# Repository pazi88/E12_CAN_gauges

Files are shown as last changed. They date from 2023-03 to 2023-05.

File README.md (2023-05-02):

# CAN-bus gauge cluster for BMW E12
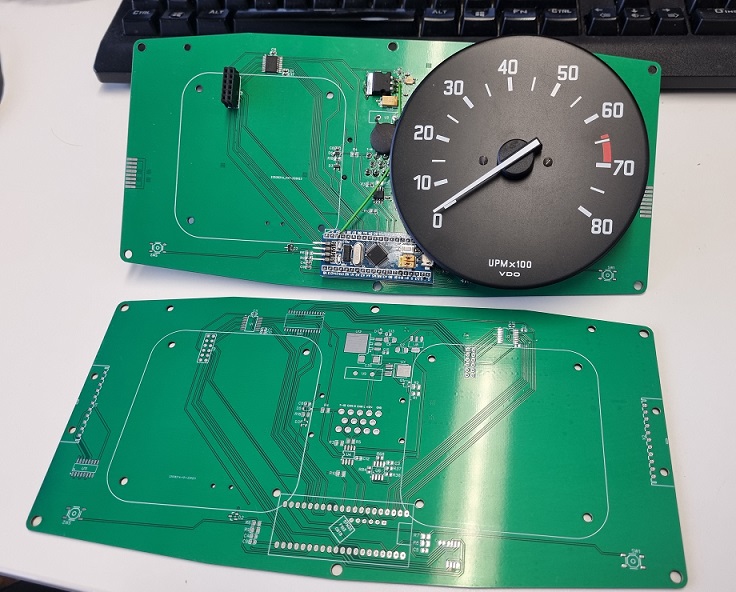
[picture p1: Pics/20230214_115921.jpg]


This is repository for CAN-bus instrument cluster for BMW E12. This is meant to replace the stock 70's mechanics/electronics inside the
cluster with x27 steppers and OLED screens to make the cluster to work with modern ECUs through CAN-bus, but retain original look.
Even though this project is meant only for E12 BMW, the code and basic circuit design can be used for other cars too.

X27.589 steppers are used to move the needles and two black and white SH1122 OLED screens are used to display odometer and trip.
The board and code can use dedicated AX1201728SG stepper driver to drive the stepper motors or TB6612FNG H-bridge driver. Both
work well, but the AX1201728SG stepper driver has micro stepping, so it will provide smoother needle movement. And allows up to 4 gauges.
MCU controlling the cluster is STM32F103C8T6 "blue pill" because of the cheap price, good availability and integrated CAN-interface.
For CAN-interface I'm using STM32 CAN library written by me: https://github.com/pazi88/STM32_CAN

CAN-bus currently supports reading data in BMW e46/e39 CAN-bus format (can11h) and also in OBD2 format.

- The OLED screen used: https://s.click.aliexpress.com/e/_DnFnmSD
- The steppers screen used: https://s.click.aliexpress.com/e/_DCNMbOH
- STM32F103C8T6: https://s.click.aliexpress.com/e/_DE6f1d3

## EasyEda
- EasyEda/OSHWLab project link for cluster back board: https://oshwlab.com/pazi88/e12_mittaristo
- EasyEda/OSHWLab project link for needle back board: https://oshwlab.com/pazi88/e12_mittaristo_copy

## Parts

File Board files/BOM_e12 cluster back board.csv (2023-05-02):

ID | Name | Designator | Footprint | Quantity | Manufacturer Part | Manufacturer | Supplier | Supplier Part | Price
1 | CR1220-2 | B1 | BAT-SMD_CR1220-2 | 1 | CR1220-2 | Q&J | LCSC | C70381 | 0.035
2 | 100nF | C1,C2,C3,C4,C5,C8,C9,C10,C11,C12,C13,C15,C16,C18,C19 | C0603 | 15 | CL10B104JB8NNNC | SAMSUNG | LCSC | C24452 | 0.001
3 | 47uF | C6,C7 | CAP-SMD_L3.5-W2.8-R-RD | 2 | CA45-B-10V-47UF-K | CEC | LCSC | C136658 | 0.015
4 | 10nF | C14,C17 | C0603 | 2 | 0603B103K500NT | FH | LCSC | C57112
5 | 10uF | C35 | CASE-E_7343 | 1 | 593D106X9050E2TE3 | Vishay Intertech | LCSC | C506619 | 0.192
6 | 776262-1 | CN1 | CONN-TH_776262-1 | 1 | 776262-1 | TE Connectivity | LCSC | C498489 | 0.88
7 | BZT52C5V6S_C173435 | D1 | SOD-323_L1.8-W1.3-LS2.5-RD | 1 | BZT52C5V6S | (MDD) Jiangsu Yutai Elec | LCSC | C173435 | 0.002
8 | BAT54CLT1G | D2,D3 | SOT-23-3_L2.9-W1.6-P1.90-LS2.8-BR | 2 | BAT54CLT1G | ON | LCSC | C14308 | 0.005
9 | BZT52C5V6_C173406 | D5 | SOD-123_L2.8-W1.8-LS3.7-RD | 1 | BZT52C5V6 | (MDD) Jiangsu Yutai Elec | LCSC | C173406 | 0.002
10 | Header-Male-2.54_2x6 | P1,P3 | HDR-TH_12P-P2.54-V-R2-C6-S2.54 | 2 |  |  | LCSC | C66689 | 0.006
11 | Serial | P2 | HDR-6X1/2.54 | 1 | Female header 1*6p | BOOMELE | LCSC | C40877 | 0.011
12 | 1K | R1,R6,R7 | R0805 | 3 | 0805W8F1001T5E | UniOhm | LCSC | C17513
13 | 4.7K | R3,R18 | R0805 | 2 | 0805W8F4701T5E | UniOhm | LCSC | C17673
14 | 10K | R4,R8,R9,R10 | R0805 | 4 | 0805W8F1002T5E | UniOhm | LCSC | C17414
15 | 120Ω | R5 | R0805 | 1 | 0805W8F1200T5E | UniOhm | LCSC | C17437
16 | 100K | R16 | R0805 | 1 | 0805W8F1003T5E | Uniroyal Elec | LCSC | C149504
17 | TS-1187A-C-G-A | SW1,SW2 | SW-SMD_4P-L5.1-W5.1-P3.70-LS6.4 | 2 | TS-1187A-C-G-A | XKB Enterprise | LCSC | C318886 | 0.009
18 | TB6612FNG(O,C,8,EL | U1,U2 | SSOP-24_L8.4-W5.8-P0.65-LS7.8-BL | 2 | TB6612FNG(O,C,8,EL | TOSHIBA | LCSC | C88224 | 0.349
19 | Blue Pill STM32F103C6T8 | U3 | BLUE PILL STM32F103C6T8 | 1
20 | MCP2551T-I/SN | U4 | SOIC-8_150MIL | 1 | MCP2551T-I/SN | MICROCHIP | LCSC | C49558 | 0.196
21 | W25Q16JVSSIQ | U5 | SOIC-8_L5.3-W5.3-P1.27-LS8.0-BL | 1 | W25Q16JVSSIQ | WINBOND | LCSC | C82317 | 0.047
22 | LD29150PT50R | U6 | TO-252-5_L6.0-W6.5-P1.27_LD29150PT50R | 1 | LD29150PT50R | ST(意法半导体) | LCSC | C3744631 | 0.159
23 | VN5R003H-E | U7 | HPAK-6_L6.1-W6.5-P0.85-LS10.0-TR | 1 | VN5R003H-E | ST(意法半导体) | LCSC | C1556752 | 0.299
24 | AMS1117-3.3 | U8 | SOT-223-3_L6.5-W3.4-P2.30-LS7.0-BR | 1 | AMS1117-3.3 | AMS | LCSC | C6186 | 0.024
25 | 14D220K | U9 | PS-RES-16.5*7.51_SMALLER | 1 | 14D220K | HEL | LCSC | C136782 | 0.011
26 | AX1201728SG | U10 | SOP-28_L17.9-W7.5-P1.27-LS10.3-BL | 1 | AX1201728SG | null | LCSC | C2841830
27 | ULN2003ADR | U11 | SOIC-16_L9.9-W3.9-P1.27-LS6.0-BL | 1 | ULN2003ADR | TI(德州仪器) | LCSC | C7512 | 0.026
28 | HEADER_POS11_?43650-1100 | X1,X2 | 43650-1100 | 2

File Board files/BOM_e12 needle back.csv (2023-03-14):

ID | Name | Designator | Footprint | Quantity | Manufacturer Part | Manufacturer | Supplier | Supplier Part | Price
1 | Header-Female-2.54_2x6 | H1 | HDR-TH_12P-P2.54-V-R2-C6-S2.54 | 1 | Header-Female-2.54_2x6 | BOOMELE | LCSC | C36191 | 0.012
2 | X27.589 | M1 | X27.589 | 1
3 | 2.08 256x64 25664 SH1122 Oled Screen Display | OLED1,OLED2 | 2.08 256X64 25664 SH1122 OLED SCREEN DISPLAY | 2 |  | Greatzt |  | 25664

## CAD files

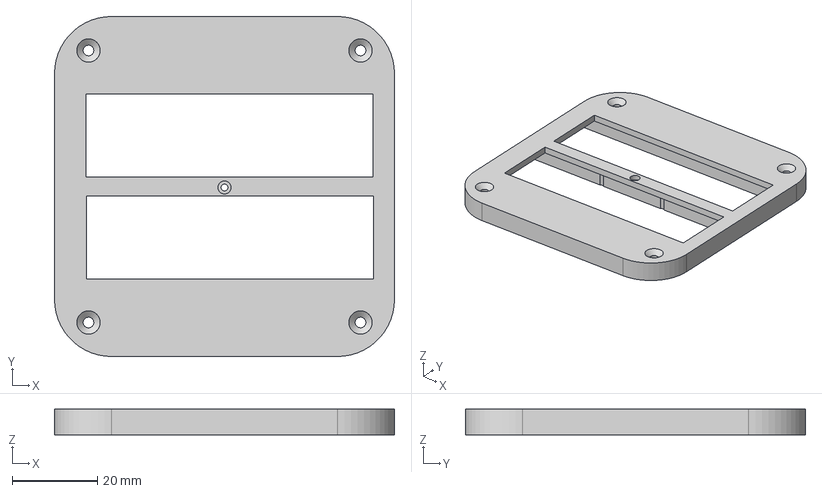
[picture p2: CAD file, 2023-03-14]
3D Models/Needle back support.step
80.0 x 80.0 x 6.00 mm

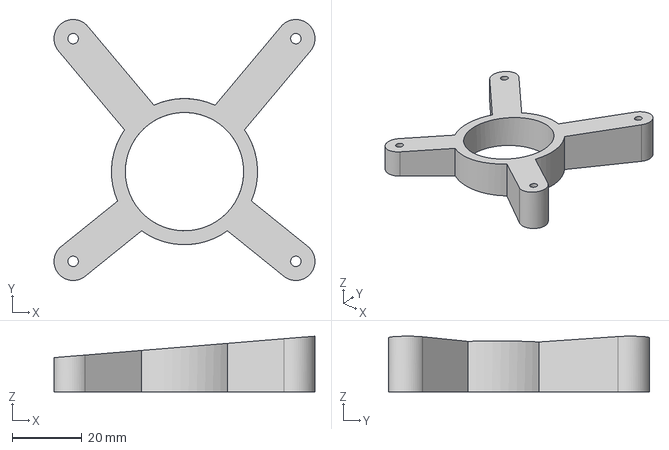
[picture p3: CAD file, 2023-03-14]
3D Models/Spacer.step
75.0 x 75.0 x 16.0 mm

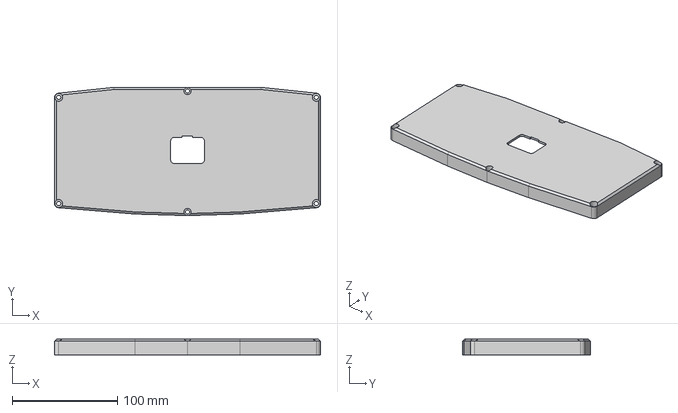
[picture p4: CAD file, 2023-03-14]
3D Models/Rear cover.step
253.0 x 122.0 x 15.0 mm

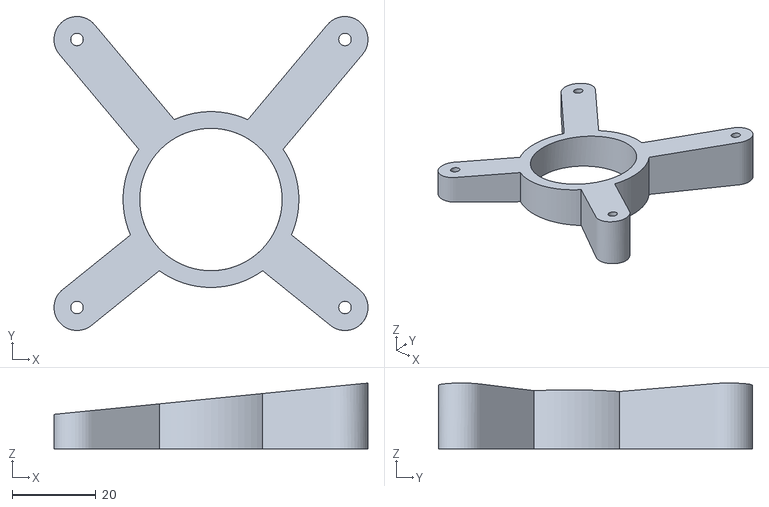
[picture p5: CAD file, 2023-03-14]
3D Models/Spacer left.stl
75.0 x 75.0 x 15.8

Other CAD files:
3D Models/Spacer right.stl
3D Models/Needle back support.stl
3D Models/Rear cover.stl

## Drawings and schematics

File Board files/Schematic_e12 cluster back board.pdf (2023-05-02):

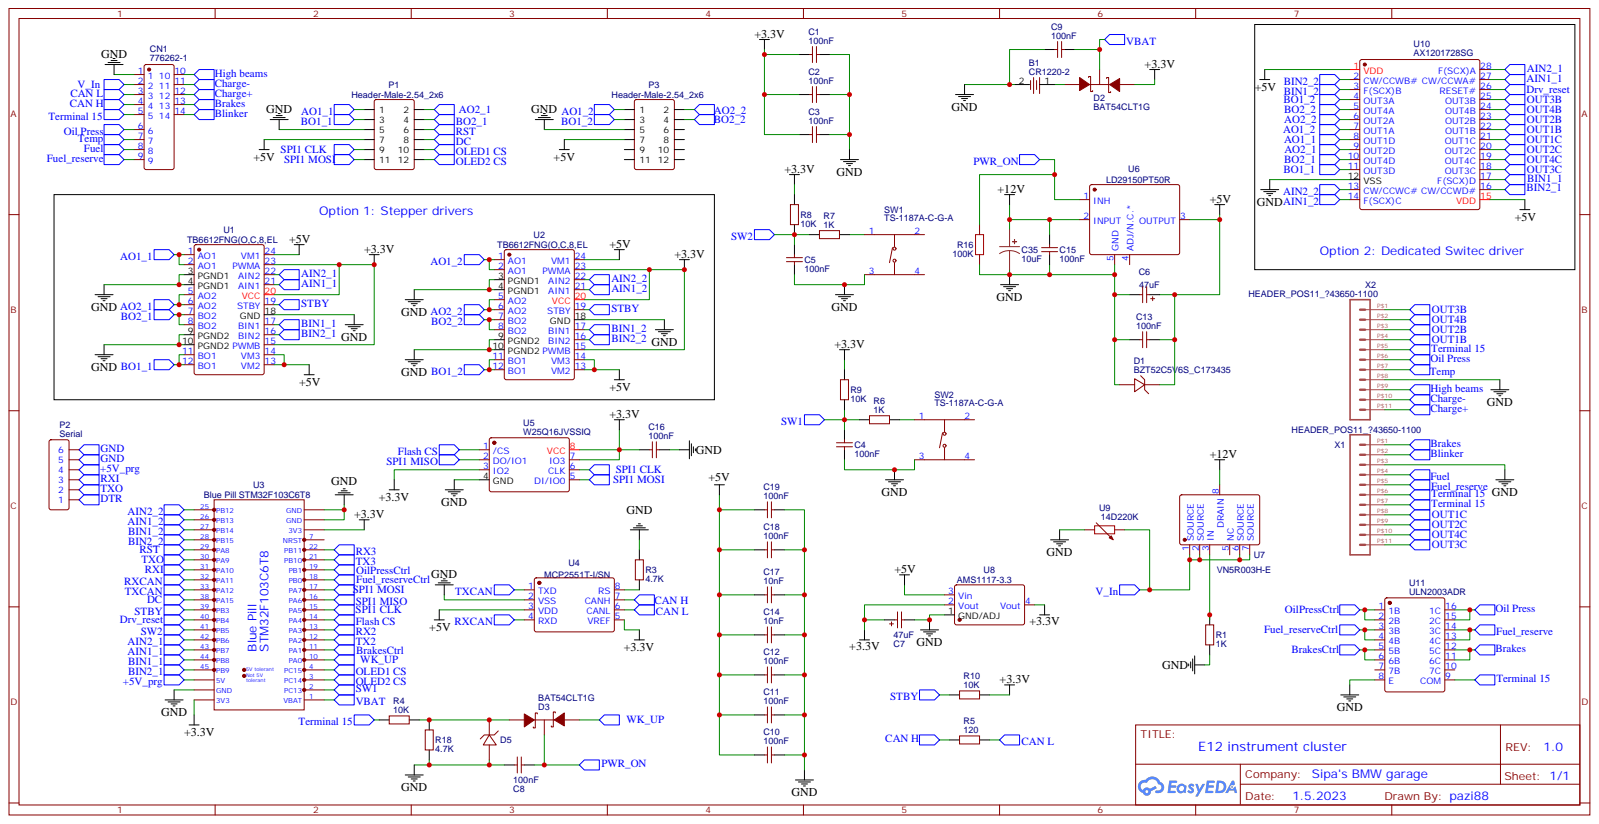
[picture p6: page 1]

Option 2: Dedicated Switec driver

Company: Sipa's BMW garage

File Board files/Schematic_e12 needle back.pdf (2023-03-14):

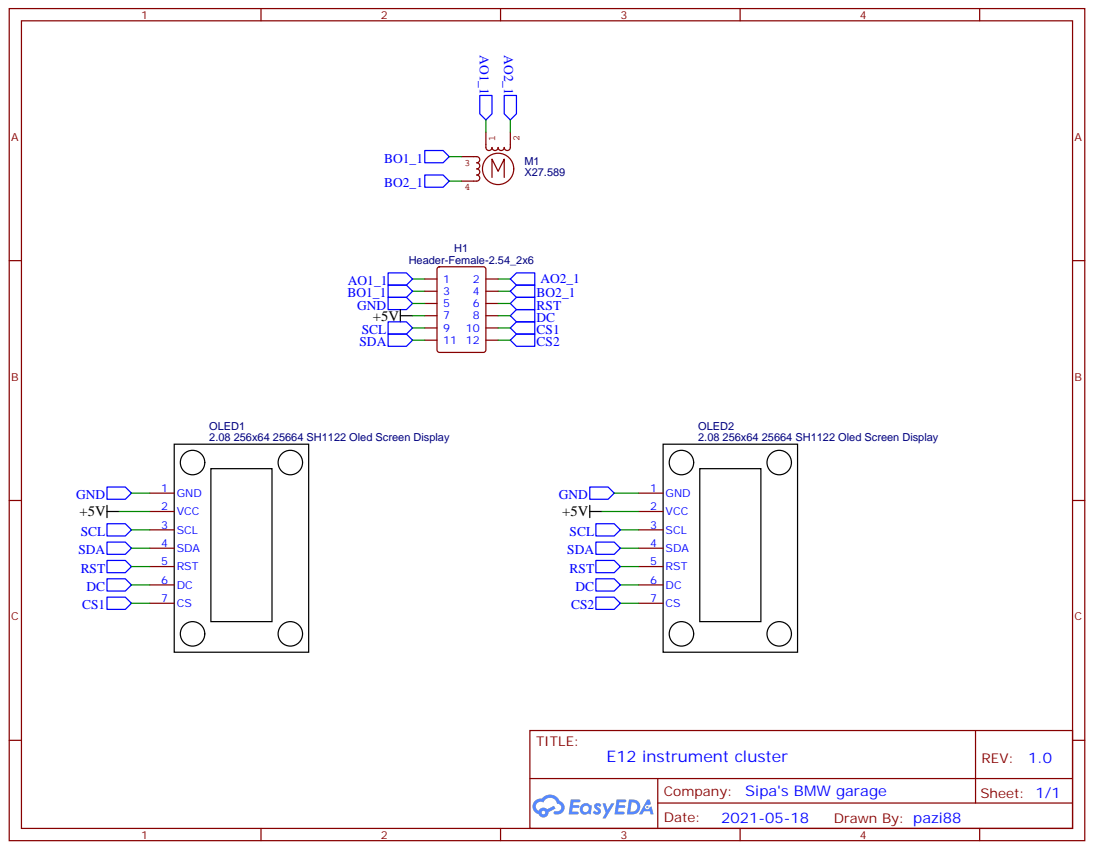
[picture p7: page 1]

Company: Sipa's BMW garage

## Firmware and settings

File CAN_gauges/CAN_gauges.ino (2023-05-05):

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
//This code is made to work with both AX1201728SG stepper driver or TB6612FNG H-bridge driver. Comment out the one that isn't used to drive the gauge steppers
#define STEPPERDRIVER
//#define HBRIDGE

#include "STM32_CAN.h" //My own STM32 CAN library
#include "U8g2lib.h" //Standard U8G2 library for the two OLEDs
#include <SPI.h> //SPI is used to talk to the screens and the Flash chip

//standard X25.168 range 315 degrees at 1/3 degree full steps
#define STEPS (315*3)

#ifdef HBRIDGE
  #include <src/SwitecX25.h>
#endif

#ifdef STEPPERDRIVER
  #include <src/SwitecX12.h>
  //With the AX1201728SG, we get microstepping, so 1/12 degree micro steps. We need this value in few places
  #define MICROSTEPS (315*12)
#endif

//this defines how much filtering is applied to the values to avoid needle jumping around. 0 = no filtering, 255 = max filtering.
#define filter_amount 5
//low pass filter stolen from speeduino code
#define FILTER(input, alpha, prior) (((long)input * (256 - alpha) + ((long)prior * alpha))) >> 8
// 50 Hz rate to update data from OBD2. This can be adjusted to suit the needs.
#define OBD2UpdateRate 50
// Custom font for the screens
const uint8_t u8g2_Super_Secret_Font_18_r[2345] U8G2_FONT_SECTION("u8g2_Super_Secret_Font_18_r") = 
  "`\0\4\4\5\5\3\5\6\30\31\0\373\22\373\23\373\3\34\6A\11\20 \6\0\20\236\0!\15D"
  "\32\236\360\0\305<\221\352A\0\42\12\7Y\257\60\244~\42\0#'M\26\276$F\230\30abD"
  "\15\31\65d\14\13n$\23#L\310\30\26l\206\10\23#L\214\60\61\302\204\14\2$-\356\262\275"
  "\27X$\252%%\214\20\11BbL\20\22D\302\225\10\227LY\302sA\320\204\71\23f\4\221 "
  "$\232,J\31:\62\0%@u\372\345BP\324\71QCF\11\23\63h\230\230A\342\304\214\21("
  "f\214\300!C\204\232\21$j\220\30\243BF\20\24#f\334\30\61\343\4\211\31&J\314\60Qb"
  "F\11;&\256\230x\0&'Q\26\312d\24\345\20\202c\6\216\31H\202 \322\223F\221\214!B"
  "b\10\31$\204\314\220*C\252\220\233Gf\12'\10\2Y\233\360 \0(\30\7w\241\64f\320\230"
  "Ac\250\31\64\15\35\315\210\14\241\251\6\215\32)\32\6s\241\60f\320\230\61d\246!B\315\234\320"
  "d\314$c\206\20\31\3\0*\25)\65\257#N\220\10!!R\30\42\64B\214\220\61\301\0+\17"
  "\254\31\302%T\256\36<\60%T\256\0,\15\4\231\235\360 \304\10\21#\204\0-\10h\264\256\360"
  " \1.\10\204\30\236\360 \0/\30j\22\252\67N\334d\343&\33\67N\334d\343&\33\67N\334"
  "\70\0\60\34M\26\276c,\215\32*H\215 \65\202\324\261;C\205j\310 \42\212R\235\1\61\14"
  "H\32\276\65\21\221\7\257\346\62\32M\26\276d*\315\22\62$HaEr$\271\312\214\225+H"
  "\360\301\203\4\63\36M\26\276c,\315\22\62$H\215 \65\222\230\271\202'\211\36;\206\250\304\22U"
  "g\0\64\35M\26\276G\260:c\247P\215 \64\204\314\30\42d\210\14\42\362\340A:\222\64\1\65"
  "\33M\26\276\242F\23\222C\247(\244f\5!\242$I\36CD\202\211\252\63\0\66!M\26\276d"
  "\14\221\22\62DF\215 \71\244\314\210#,\312\220 \205+\22d\210\254Iu\6\0\67\23L\26\276"
  "\360\203\201S\16\34Hp \205\3\351\25\0\70!M\26\276c,\315\222A$H\215 \65d\324\20"
  "U\207V\20\42\61\354\62TI\212(B\3\0\71\42M\26\276c\14\221\22B$H\215\30\66b\30"
  "*D%\270)Ar\304\260\21\204\210P\223\314\20\0:\13\244\31\236\360 <\250\7\1;\21$\232"
  "\235\360 <\250\7!F\210\30!\4\0<\24\255\25\302\34t\234\251\63\207\216\221\64y\360\244I\302"
  "\1=\14\14Y\302\360 =d\17\36\30>\25\255\25\302 \226\344\301\223\7\215\216\63u\6\315\261\202"
  "b\1?\30l\26\272%\16\215\212\42\211\20\235\42W\254v\4\251\7E\220F\0@\71s\26\326)"
  "<!\263\201\203\206\216\21SB\222!ID\10\241D\204\220AbJ\214\22Sb\224\30\21\42\6\15"
  "\221b\320\20!#\30\11Q\65&\32A\3\207\261D\5\0A$R\22\312G\274\260\341\243HI\14"
  "\35B\220\10A\62\343\10\21#D\254\221G\3\211\20$B\220\4Q\2B\36O\32\312\300\306\205\13"
  "b$\310\215 \67\202\30\211&M\134\20K\207\263\7\17H\260\1C!q\26\316(\30\35#\67\205"
  "\212\24+A\60\61iZ\27$A\220D\261\42\205\312\264b\207\10\0D\31P\32\316\260\252\215\23R"
  "&\310\221 \227\20G\202\224\11'mV\1E\22N\32\306\360\203\240\64m\321\5Q:}\360\200"
  "\1F\20M\32\302\360AKZ\262\340\5I\372\22\0G\42q\26\322(\30\35#\67\205\212\24#B"
  "\60\61iR\134\65$A\220D\71\42\245\212\274qud\0H\17O\32\322@\16\277{\360\1:\374"
  "\35\1I\10D\32\242\360\7\14J\24L\26\276H\377\341\251S#\6\221 CbI\242\63\0K+"
  "Q\32\316@\256\4\261\42\244\312\20*D\246\24\221b$\312%T\267\314D\251\62\244\10\25\42U\206"
  "\30\31bE\310\225 X\0L\15M\32\302@\222\376\277|\360 \1M)T\32\342`\220a\63\317"
  "\36=\10\64\2\305\240\21(\210\220@Ad\10\222Ipr\6\215\31\64f\320\24BD\10\21\5N"
  "\37O\32\322@\20]\262d\252\26-:A\346\310\230#D\316\220\70C\342\320*\315\322\241#O!"
  "r\26\322(:\35+G\245\212\224#BP%R\234\246$A\260D\71\62\245\312\270b\210\12\0P"
  "\31O\32\306\260\250\211\13b$\310\215 \207\31\11\27M\330$#Ko\1Q$\222\366\321(:\35"
  "+G\245\212\224#BP%R\234\246$AJD\65h\312\234q\345\14\5y\0\42\0R\26O\32"
  "\316\320\304\305\3b\351p\367`D\23\27\304\322\341\303\1S\36o\26\306\27\64\325\232&\244\210\214#"
  "A\326d\272e\12\221\246C\227\214D\33Fi\0T\14O\22\302\360\63\262\364\377\25\0U\22P\32"
  "\322@\20\377\17\223\21!U\304\15\253D\0V&P\22\306@\220\4\71\22\344H\20#C\212\14)"
  "\62\204H\221!E\206\24\21r$\310\221 \207\362J\263U\1W<X\22\342@\214\12R\304H\220"
  "*D\204\220!\42\204\14\221!c\210\14\231\63\203\210\220\30Bj\310$\244\206\314\214\304\20\22\303\320"
  "\234\63t\316\220AC\6M\225$V\222\30)\0X&P\26\312P\254\4\61\62\204\10\25)E\204"
  "\34B\224f\311\232<\211\216D\251\42\244\310\224!U\242\30\11r\5Y\33Q\22\302@P\35\221R"
  "\204\10UC\214H\261\22\4\221\36\65L\232~\7\0Z\17O\26\306\341K\223\365\322d=}\360\1"
  "[\15\7{\245\360 \321\374\377\243\7\6\134\31i\22\252\60l\234\270a\343\206M\67l\234\270a\343"
  "\206M\67l\234\0]\15\7s\245\360\300\14\375\377\233\7\12^\25L\31\303D\220\234\61SCD\15"
  "\31\63\243!\203F\14\33_\7,\260\261\300\0`\11e\360\237@d\314\0a\34\255\25\276\222f\11"
  "\31\22\244F\222B\262\242\320\10R#\10\221 D\202\311\11\2b\32M\32\302\60t^\230YR\5"
  "\251\21\303\356\14\21\211\42%\226\214\60\3\0c\27\255\25\276\203HI\25\204\220\235\244\331\10B$\212"
  "\220Qt\6\0d\31M\26\302:oL\14YQ\244\4!dw\66\202\20\211\42E\326\230\30e\30"
  "\255\25\276s*\15%\243P=x@\222\350\260\21E\310(:\3\0f\22I\22\246T\306\310\21R"
  "dP\240!E\377\15\0g!Mv\301cb\310\12\62%F!\273+\22dJ\60\71\61J\314\320"
  "\21\243H\24!\223\314\14\0h\21L\32\302\60r^\234XQ$\321\251\373+\2i\12C\32\236\220"
  "\354\301\203\4j\17\346r\235Bs\42\364\377\202D\25\202\0k L\32\276\60r\36\221\30Cd\10"
  "\231\21\204N!BD\202\314\30\42c\210\14\42\61\10\25\1l\10C\32\236\360\203\4m&\264\31\336"
  "\60\302\210\221\7$\212\30!A\210\320)B\247F\235\32uj\324\251Q\247F\235\32uj\324\251Q"
  "\4n\17\254\31\302\60\342\304\212\42\211N\335_\21o\27\256\25\302\203JM\221\42\243H\20\303\63\22"
  "\204\210T\243\12\15\0p\33Mz\301\60\302\314\222*H\215\30vg\210H\24)\261d\204\231\241s"
  "\12\0q\31Mv\301cb\310\212\42%\10!\273\263\21\204H\24)\262\306\304\320yr\17\250\31\252"
  "\60\304\304\3\61\204F\315\257\0s\26\254\25\272\202F\5\241\21\204\22\242Jv\360\24\42\22j\220\0"
  "t\21)\22\246B\212\66\17\206\220\242_\235\61T\0u\17\254\31\302\60\352\376\12Q\12\27#\214\14"
  "v\34\255\21\266@\212\4!\22\204\206\220!\63\206\222QCF\215 u\316\272\222\204\0w+\264\25"
  "\326\60\212\20\42B#\310\224!\62\246\14\21\42F\306\220\230d\320\210)\10\215\230\325\21Sf\214\225"
  ")W\210\34)B\0x\31\255\21\272A\210\10\65$H!\63W\260\240\261S$\10\21\241\10\25\1"
  "y#Mr\265@l\304(\22\204\206\20\32\63\206\222ADF\215 u\316\134\301\222$G\22;f"
  "\216 \0z\16\254\25\272\260b\273b\365\335\203\7\6{\26\11s\245E\306\310\21R\364Q\231B\245"
  "\210\221\242\257\316\230\42|\10\3w\231\360\7\14}\32\11s\245@\252\220)b\363\214\24\261BeH"
  "\221\32\66Wd\254!\5\0~\15\254\230\302\42\322L\10\67\6\207\0/q\26\316\360`<\0\361"
  "\0\304\3\20\17@<\0\361\0\304\3\20\17@<\0\361\0\304\3\20\17@<\0\361\0\304\3\20\17"
  "@<\200\7\3\0\0\0";

static CAN_message_t CAN_outMsg;
static CAN_message_t CAN_inMsg;

static uint32_t RPM_timeout=millis();   // for the RPM timeout
static uint32_t VSS_timeout=millis();   // for the VSS timeout
//CAN rx buffer size increased, because it might be needed in busy CAN bus.
STM32_CAN Can1( CAN1, DEF, RX_SIZE_64, TX_SIZE_16 );

#define FLASH_BASEADRESS     0x801D400UL
#define FLASH_ODOADRESS      0x801D404UL

U8G2_SH1122_256X64_1_4W_HW_SPI upper(U8G2_R2, /* cs=*/ PC15, /* dc=*/ PA15, /* reset=*/ PA8); // Screen above the needle
U8G2_SH1122_256X64_1_4W_HW_SPI lower(U8G2_R2, /* cs=*/ PC14, /* dc=*/ PA15, /* reset=*/ U8X8_PIN_NONE); // Screen below the needle. (screens share the reset pin)

// for motors connected to digital pins
#ifdef HBRIDGE
  SwitecX25 VSSGauge(STEPS,PB6,PB7,PB9,PB8);
  SwitecX25 RPMGauge(STEPS,PB12,PB13,PB15,PB14);
#endif

#ifdef STEPPERDRIVER
  SwitecX12 VSSGauge(MICROSTEPS, PB8, PB9, 1);
  SwitecX12 RPMGauge(MICROSTEPS, PB6, PB7, 1);
  SwitecX12 CLTGauge(MICROSTEPS, PB14, PB15, 0);
  SwitecX12 FUELGauge(MICROSTEPS, PB13, PB12, 0);
#endif

// to keep track of if OBD2 requests have been sent.
bool RPM_Request=true;
bool VSS_Request=true;
bool CLT_Request=true;

uint16_t VSS,RPM,RPMsteps,VSSsteps,CLTsteps,FUELsteps;
// odometer value shown on screen. 1km resolution
uint32_t odometer;
uint32_t odometerOld;
// trip value shown on screen. 100m resolution
uint16_t trip;
uint16_t tripOld;
// more accurate trip and odometer. 1cm resolution.
uint64_t odometerCm;
uint64_t odometerCmStart;
uint32_t tripCm;
uint32_t tripCmStart;
// to keep track of 1sec duration to calculate trip and odometer.
int8_t oneSec;
// Extra values to keep track of.
uint8_t CLT;
uint8_t FUEL;
uint8_t TPS;
// for now program memory flash is used to store odometer/trip. It has wear limit, so we try to avoid writing to it as much as possible. So this makes the flash to be written only once on every power up.
bool notCommitted;
// push buttons on the instrument cluster
const int leftButton = PC13;
const int rightButton = PB5;
// the instrument cluster can be kept on using this pin as output to drive home the needles.
const int powerPin = PA0;
// instrument cluster lights.
const int oilPressLight = PB1;
const int fuelReserveLight = PB0;
const int brakeLight = PA1;

#if ((STM32_CORE_VERSION_MINOR<=8) & (STM32_CORE_VERSION_MAJOR==1))
void requestData(HardwareTimer*){void requestData();}
void updateSteppers(HardwareTimer*){void updateSteppers();}
#endif

void updateSteppers()
{
  // the gauges only moves when update is called. So we call the update on this fuction for every 100uS.
  VSSGauge.update();
  RPMGauge.update();
  #ifdef STEPPERDRIVER
  CLTGauge.update();
  FUELGauge.update();
  #endif
}

// called in 1 second intervals to calculate driven distance.
void calcOdometer()
{
  uint32_t VSScmS = (VSS-256)/4.608; // Looks bit weird but this is the BMW VSS data converted to centimeters per second. This comes from the bmw to km/h ( (/128)-2 ) conversion and the km/h to m/s conversion ( /3.6 )
  odometerCm = odometerCm + VSScmS; // Because this is called in 1sec intervals, we just add the driven distance to the count.
  tripCm = tripCm + VSScmS; // Same for trip.
  odometer = odometerCm / 100000; // Convert centimeters to kilometers for odometer
  trip = tripCm / 10000; // Convert centimeters to 100 meters for trip.
}

void requestData()
{
  if(RPM_Request) {
    CAN_outMsg.buf[2]= 0x0C; // PID number for RPM
    Can1.write(CAN_outMsg);
    RPM_Request = false;
  }
  
  if(VSS_Request) {
    CAN_outMsg.buf[2]= 0x0D; // PID number for VSS
    Can1.write(CAN_outMsg);
    VSS_Request = false;
  }
  
  if(CLT_Request) {
    CAN_outMsg.buf[2]= 0x05; // PID number for CLT
    Can1.write(CAN_outMsg);
    CLT_Request = false;
  }
  oneSec++;
  // check if one second has passed
  if ( oneSec >= OBD2UpdateRate ) {
    calcOdometer();
	oneSec = 0;
  }
}

void read_trip( uint32_t *data ) {
  uint32_t* base_addr = (uint32_t *) FLASH_BASEADRESS; 
  *(data) = *(base_addr);
}

void read_odometer( uint64_t *data ) {
  uint64_t* base_addr = (uint64_t *) FLASH_ODOADRESS;
  *(data) = *(base_addr);
}

void setup(void)
{
  // initialize screens
  upper.begin();
  lower.begin();
  read_odometer(&odometerCm);
  odometerCmStart = odometerCm;
  odometer = odometerCm / 100000;
  odometerOld = odometer;
  read_trip(&tripCm);
  tripCmStart = tripCm;
  trip = tripCm / 10000;
  tripOld = trip;
  Serial.begin(115200); // for debugging
  // Init CAN
  Can1.begin();
  Can1.setBaudRate(500000);
  // Filter out unwanted CAN messages.
  Can1.setMBFilterProcessing( MB0, 0x316, 0x1FFFFFFF );
  Can1.setMBFilterProcessing( MB1, 0x329, 0x1FFFFFFF );
  Can1.setMBFilterProcessing( MB2, 0x153, 0x1FFFFFFF );
  Can1.setMBFilterProcessing( MB3, 0x7E8, 0x1FFFFFFF );
  CAN_outMsg.len = 8; // 8 bytes in can message
  CAN_inMsg.len = 8;
  CAN_outMsg.id = 0x7df; // OBD-II PID_REQUEST
  CAN_outMsg.buf[0]= 0x02; // Sending 2 bytes
  CAN_outMsg.buf[1]= 0x01; // Mode 01 "Show current data"
  CAN_outMsg.buf[2]= 0x00; // set to zero just in case.
  CAN_outMsg.buf[3]= 0x00; // set to zero just in case.
  CAN_outMsg.buf[4]= 0x00; // set to zero just in case.
  CAN_outMsg.buf[5]= 0x00; // set to zero just in case.
  CAN_outMsg.buf[6]= 0x00; // set to zero just in case.
  CAN_outMsg.buf[7]= 0x00; // set to zero just in case.
  
  VSS = 0;
  RPM = 0;
  RPMsteps = 0;
  VSSsteps = 0;
  oneSec = 0;
  CLT = 0;
  TPS = 0;
  notCommitted = true;
  RPMGauge.setPosition(0);
  VSSGauge.setPosition(0);

  // setup hardwaretimer to request obd data in 50Hz pace. Otherwise the obd2 requests can be too fast. This timer is also used to calculate odometer and trip in 1sec intervals.
#if defined(TIM1)
  TIM_TypeDef *Instance1 = TIM1;
#else
  TIM_TypeDef *Instance1 = TIM2;
#endif
  TIM_TypeDef *Instance2 = TIM3;
  HardwareTimer *requestTimer = new HardwareTimer(Instance1);
  HardwareTimer *stepperTimer = new HardwareTimer(Instance2);
  requestTimer->setOverflow(OBD2UpdateRate, HERTZ_FORMAT);
  stepperTimer->setOverflow(10000, HERTZ_FORMAT);
#if ( STM32_CORE_VERSION_MAJOR < 2 )
  requestTimer->attachInterrupt(1, requestData);
  requestTimer->setMode(1, TIMER_OUTPUT_COMPARE);
  stepperTimer->attachInterrupt(1, updateSteppers);
  stepperTimer->setMode(1, TIMER_OUTPUT_COMPARE);
#else //2.0 forward
  requestTimer->attachInterrupt(requestData);
  stepperTimer->attachInterrupt(updateSteppers);
#endif
  requestTimer->resume();
  stepperTimer->resume();

  // put the odometer and trip values from memory to the screens.
  updateOdometer();
  updateTrip();
  // set the basic inputs/outputs
  pinMode(leftButton, INPUT);
  pinMode(rightButton, INPUT);
  pinMode(powerPin, OUTPUT);
  pinMode(oilPressLight, OUTPUT);
  pinMode(fuelReserveLight, OUTPUT);
  pinMode(brakeLight, OUTPUT);
  // the power pin is set to high to keep the instrument cluster powered on when ignition is turned off. This code will shut down the cluster once needles are at zero.
  digitalWrite(powerPin, HIGH);
  // Set all the lights off by default
  digitalWrite(oilPressLight, HIGH);
  digitalWrite(fuelReserveLight, HIGH);
  digitalWrite(brakeLight, HIGH);
  Serial.println("Setup done");
}

void updateOdometer()
{
  upper.firstPage();
  // we put the odometer reading to the array so that the numbers are in same location, no matter what the odometer reading is.
  int8_t odometer_array[7];
  int8_t j = 0;
  for(uint32_t i = 1000000; i > 0; i /= 10) {
    odometer_array[j] = int8_t((odometer/i) % 10 );
    j++;
  }
  // update the values from the array to the screen
  do {
    upper.setFont(u8g2_Super_Secret_Font_18_r);
    bool first_digit = false;
    for (int i=0; i<7; i++)
    {
      if ( (odometer_array[i] > 0) || first_digit || (i == 6) ) // do not draw the leading zeros
      {
        first_digit = true;
        upper.setCursor((65+((i-1)*20)), 38);
        upper.print(odometer_array[i]);
      }
    }
  } while ( upper.nextPage() );
  // set the old value to same as the current so that we can keep track when this changes.
  odometerOld = odometer;
}

void updateTrip()
{
  lower.firstPage();
  // we put the trip reading to the array so that the numbers are in same location, no matter what the trip reading is.
  int8_t trip_array[4];
  int8_t j = 0;
  for(uint16_t i = 1000; i > 0; i /= 10) {
    trip_array[j] = int8_t((trip/i) % 10 );
    j++;
  }
  // update the values from the array to the screen
  do {
    lower.setFont(u8g2_Super_Secret_Font_18_r);
    bool first_digit = false;
    for (int i=0; i<4; i++)
    {
      if ( (trip_array[i] > 0) || first_digit || (i == 3) ) // do not draw the leading zeros
      {
        first_digit = true;
        lower.setCursor((113+((i-1)*20)), 42);
        lower.print(trip_array[i]);
      }
    }
  } while ( lower.nextPage() );
  // set the old value to same as the current so that we can keep track when this changes.
  tripOld = trip;
}

void CalcRPMgaugeSteps()
{
  uint16_t tempRPMsteps = 0;
  // RPM gauge face is not linear. Below 1000 RPM has different scale than above it.
  if ( RPM < 6400 ) // < 1000rpm
  {
    tempRPMsteps = map(RPM, 0, 6400, 0, 50);
  }
  else if ( RPM < 63616 ) // >= 1000rpm
  {
    tempRPMsteps = map(RPM, 6400, 63616, 50, STEPS);
  }
  else if ( RPM >= 63616 )// limit to max steps
  {
    tempRPMsteps = STEPS;
  }
#ifdef STEPPERDRIVER
  tempRPMsteps = tempRPMsteps * 4;
#endif
  // low pass filter the step value to prevent the needle from jumping.
  RPMsteps = FILTER(tempRPMsteps, filter_amount, RPMsteps);
  RPMGauge.setPosition(RPMsteps);
}

void CalcVSSgaugeSteps()
{
  uint16_t tempVSSsteps = 0;
  // VSS gauge face is even less linear. This looks horrible, but it works.
  if ( VSS < 2816 ) // < 20km/h, Minimum is 20km/h. Less than that we set gauge at zero steps.
  {
    tempVSSsteps = 0;
  } 
  else if ( VSS < 5376 ) // < 40km/h
  {
    tempVSSsteps = map(VSS, 2816, 5376, 0, 76);
  }
  else if ( VSS < 7936 ) // < 60km/h
  {
    tempVSSsteps = map(VSS, 5376, 7936, 76, 150);
  }
  else if ( VSS < 10496 ) // < 80km/h
  {
    tempVSSsteps = map(VSS, 7936, 10496, 150, 221);
  }
  else if ( VSS < 13056 ) // < 100km/h
  {
    tempVSSsteps = map(VSS, 10496, 13056, 221, 296);
  }
  else if ( VSS < 15616 ) // < 120km/h
  {
    tempVSSsteps = map(VSS, 13056, 15616, 296, 370);
  }
  else if ( VSS < 18176 ) // < 140km/h
  {
    tempVSSsteps = map(VSS, 15616, 18176, 370, 443);
  }
  else if ( VSS < 20736 ) // < 160km/h
  {
    tempVSSsteps = map(VSS, 18176, 20736, 443, 517);
  }
  else if ( VSS < 23296 ) // < 180km/h
  {
    tempVSSsteps = map(VSS, 20736, 23296, 517, 592);
  }
  else if ( VSS < 25856 ) // < 200km/h
  {
    tempVSSsteps = map(VSS, 23296, 25856, 592, 670);
  }
  else if ( VSS < 35200 ) // >= 200km/h
  {
    tempVSSsteps = map(VSS, 25856, 35200, 670, STEPS);
  }
  else // limit to max steps
  {
    tempVSSsteps = STEPS;
  }
#ifdef STEPPERDRIVER
   tempVSSsteps =  tempVSSsteps * 4;
#endif
  // low pass filter the step value to prevent the needle from jumping.
  VSSsteps = FILTER(tempVSSsteps, filter_amount, VSSsteps);
  VSSGauge.setPosition(VSSsteps);
}

#ifdef STEPPERDRIVER
void CalcCLTgaugeSteps()
{
  uint16_t tempCLTsteps = 0;
  tempCLTsteps = map(CLT, 60, 120, 0, MICROSTEPS);
  // low pass filter the step value to prevent the needle from jumping.
  CLTsteps = FILTER(tempCLTsteps, filter_amount, CLTsteps);
  VSSGauge.setPosition(CLTsteps);
}

void CalcFuelgaugeSteps()
{
  uint16_t tempFuelSteps = 0;
  tempFuelSteps = map(FUEL, 0, 255, 0, MICROSTEPS);
  // low pass filter the step value to prevent the needle from jumping.
  FUELsteps = FILTER(tempFuelSteps, filter_amount, FUELsteps);
  FUELGauge.setPosition(FUELsteps);
}
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
void loop(void)
{
  // check if the pushbuttons are pressed.
  if (digitalRead(leftButton) == LOW) {
    // zero out the trip
    trip = 0;
	tripCm = 0;
  }

  if ( (millis()-RPM_timeout) > 500) { // timeout, because no RPM data from CAN bus
    RPM_timeout = millis();
    RPM = 0;
    RPMGauge.setPosition(0);
    RPM_Request = true;
    Serial.println ("RPM timeout");
	// no RPM data, so we assume that the car has shut down. So proceed to shut down the cluster too.
	Serial.println ("Shutdown started");
	clusterShutdown();
  }
  if ( (millis()-VSS_timeout) > 500) { // timeout, because no VSS data from CAN bus
    VSS_timeout = millis();
    VSS = 0;
    VSSGauge.setPosition(0);
    VSS_Request = true;
    Serial.println ("VSS timeout");
  }
  
  // update the screens if the odometer and trip values have changed, because those are dead slow to update
  if ( odometer > odometerOld ) {
    updateOdometer();
  }
  if ( trip != tripOld ) {
    updateTrip();
  }

  // see if there is messages available on can bus to read.
  while (Can1.read(CAN_inMsg) ) {
    readCanMessage();
  }
}

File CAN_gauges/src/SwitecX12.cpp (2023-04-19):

/*
 *  SwitecX12 Arduino Library
 *  Guy Carpenter, Clearwater Software - 2017
 *
 *  Licensed under the BSD2 license, see license.txt for details.
 *
 *  All text above must be included in any redistribution.
 */
 
 // modified by pazi88

#include <Arduino.h>
#include "SwitecX12.h"

// This table defines the acceleration curve.
// 1st value is the speed step, 2nd value is delay in microseconds
// 1st value in each row must be > 1st value in subsequent row
// 1st value in last row should be == maxVel, must be <= maxVel
static unsigned short defaultAccelTable[][2] = {
  {   5, 3100},
  {  10, 2500},
  {  15, 2000},
  {  20, 1600},
  {  30, 1300},
  {  40, 1000},
  {  50, 800},
  {  60, 620},
  {  70, 490},
  {  80, 390},
  {  90, 310},
  { 100, 240},
  { 110, 190},
  { 120, 150},
  { 130, 120},
  { 140, 90}
};

const int stepPulseMicrosec = 1;
const int resetStepMicrosec = 300;
#define DEFAULT_ACCEL_TABLE_SIZE (sizeof(defaultAccelTable)/sizeof(*defaultAccelTable))

SwitecX12::SwitecX12(unsigned int steps, unsigned char pinStep, unsigned char pinDir, bool invert)
{
  this->steps = steps;
  this->pinStep = pinStep;
  this->pinDir = pinDir;
  this->invert = invert;
  pinMode(pinStep, OUTPUT);
  pinMode(pinDir, OUTPUT);
  digitalWrite(pinStep, LOW);
  if (invert) { digitalWrite(pinDir, HIGH); }
  else { digitalWrite(pinDir, LOW); }
  pinMode(13, OUTPUT);

  dir = 0;
  vel = 0;
  stopped = true;
  currentStep = 0;
  targetStep = 0;

  accelTable = defaultAccelTable;
  maxVel = defaultAccelTable[DEFAULT_ACCEL_TABLE_SIZE-1][0]; // last value in table.
}

void SwitecX12::step(int dir)
{
  if (invert) { digitalWrite(pinDir, dir > 0 ? HIGH : LOW); }
  else { digitalWrite(pinDir, dir > 0 ? LOW : HIGH); }
  digitalWrite(13, vel == maxVel ? HIGH : LOW);
  digitalWrite(pinStep, HIGH);
  delayMicroseconds(stepPulseMicrosec);
  digitalWrite(pinStep, LOW);
  currentStep += dir;
}

void SwitecX12::stepTo(int position)
{
  int count;
  int dir;
  if (position > currentStep) {
    dir = 1;
    count = position - currentStep;
  } else {
    dir = -1;
    count = currentStep - position;
  }
  for (int i=0;i<count;i++) {
    step(dir);
    delayMicroseconds(resetStepMicrosec);
  }
}

void SwitecX12::zero()
{
  currentStep = steps - 1;
  stepTo(0);
  targetStep = 0;
  vel = 0;
  dir = 0;
}

void SwitecX12::advance()
{
  // detect stopped state
  if (currentStep==targetStep && vel==0) {
    stopped = true;
    dir = 0;
    time0 = micros();
    return;
  }

  // if stopped, determine direction
  if (vel==0) {
    dir = currentStep<targetStep ? 1 : -1;
    // do not set to 0 or it could go negative in case 2 below
    vel = 1;
  }

  step(dir);

  // determine delta, number of steps in current direction to target.
  // may be negative if we are headed away from target
  int delta = dir>0 ? targetStep-currentStep : currentStep-targetStep;

  if (delta>0) {
    // case 1 : moving towards target (maybe under accel or decel)
    if (delta < vel) {
      // time to declerate
      vel = delta;
    } else if (vel < maxVel) {
      // accelerating
      vel++;
    } else {
      // at full speed - stay there
    }
  } else {
    // case 2 : at or moving away from target (slow down!)
    vel--;
  }

  // vel now defines delay
  unsigned char i = 0;
  // this is why vel must not be greater than the last vel in the table.
  while (accelTable[i][0]<vel) {
    i++;
  }
  microDelay = accelTable[i][1];
  time0 = micros();
}

void SwitecX12::setPosition(unsigned int pos)
{
  // pos is unsigned so don't need to check for <0
  if (pos >= steps) pos = steps-1;
  targetStep = pos;
  if (stopped) {
    // reset the timer to avoid possible time overflow giving spurious deltas
    stopped = false;
    time0 = micros();
    microDelay = 0;
  }
}

void SwitecX12::update()
{
  if (!stopped) {
    unsigned long delta = micros() - time0;
    if (delta >= microDelay) {
      advance();
    }
  }
}

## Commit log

2023-03-14 Add board files
    [BOM_e12 cluster back board.csv, BOM_e12 needle back.csv]
2023-03-14 Add 3D models
    [Needle back support.step, Needle back support.stl, Rear cover.step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]
2023-04-19 Switch to custom library to use the stepper driver
2023-04-24 CAN message filtering
2023-04-27 Fix bug in VSS
    [CAN_gauges.ino]
2023-05-02 Update board files
    [BOM_e12 cluster back board.csv]
